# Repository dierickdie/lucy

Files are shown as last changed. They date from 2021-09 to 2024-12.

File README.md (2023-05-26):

# Lucy
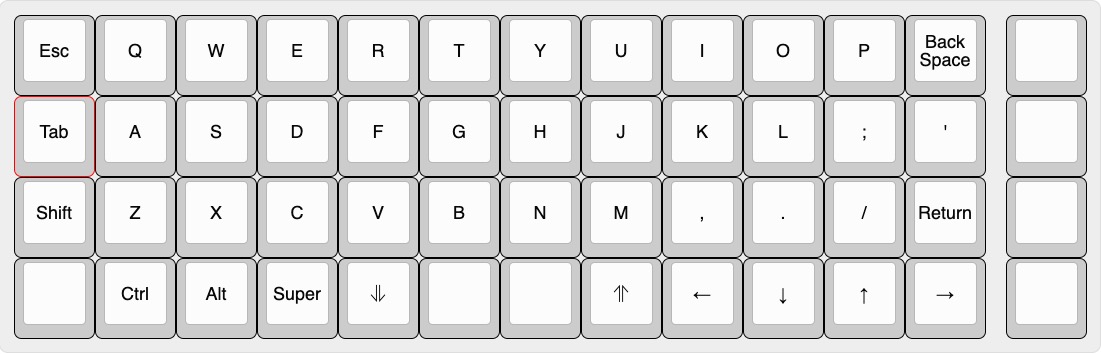
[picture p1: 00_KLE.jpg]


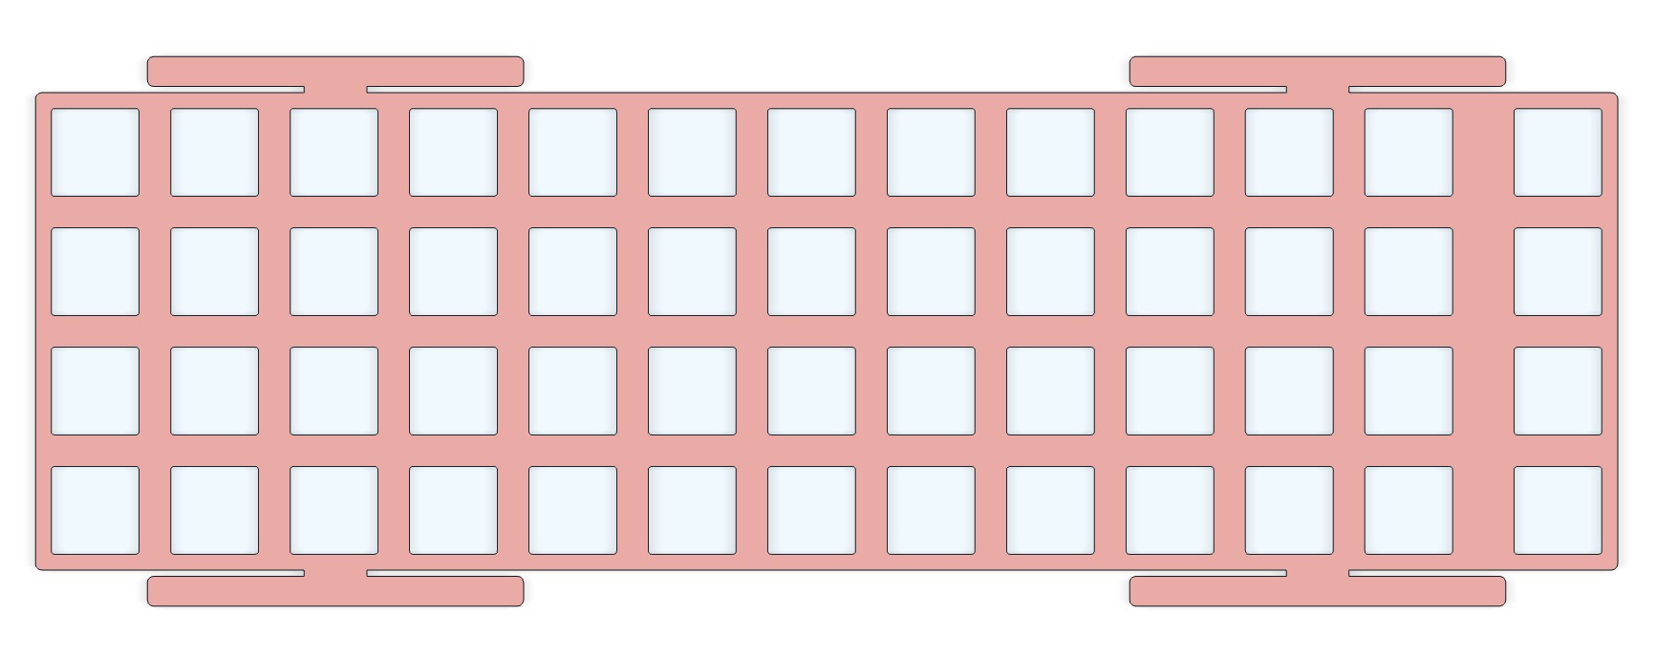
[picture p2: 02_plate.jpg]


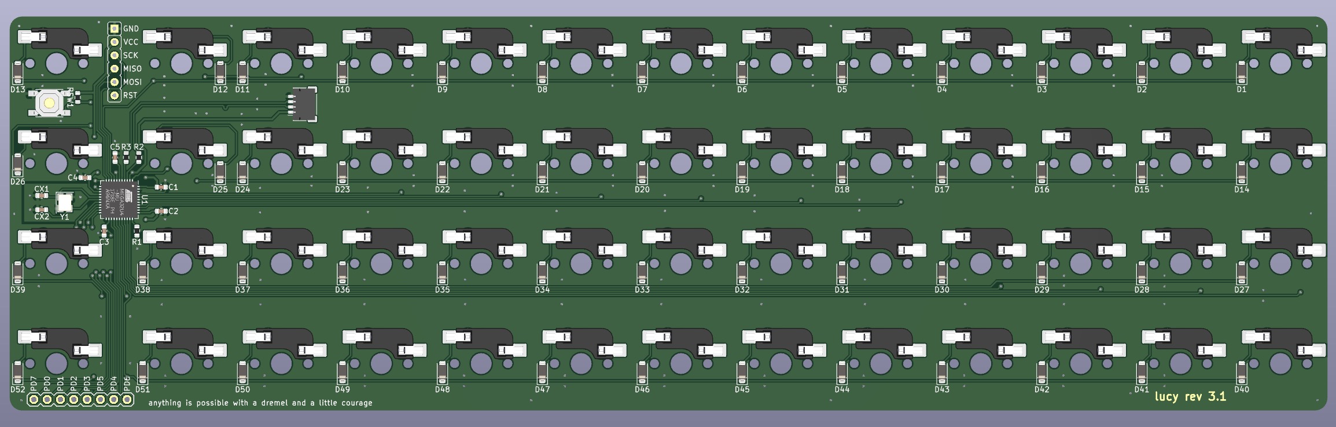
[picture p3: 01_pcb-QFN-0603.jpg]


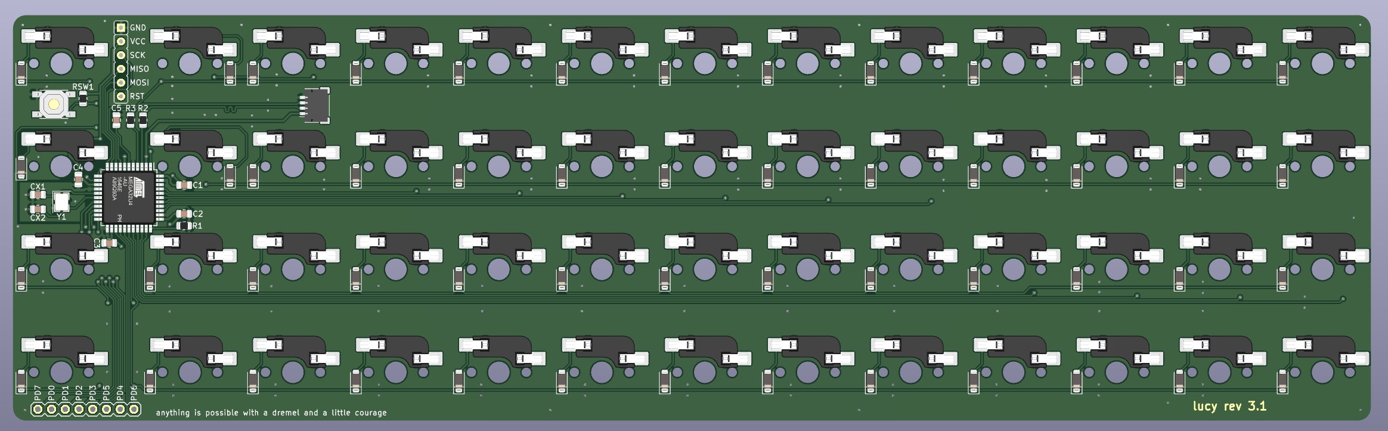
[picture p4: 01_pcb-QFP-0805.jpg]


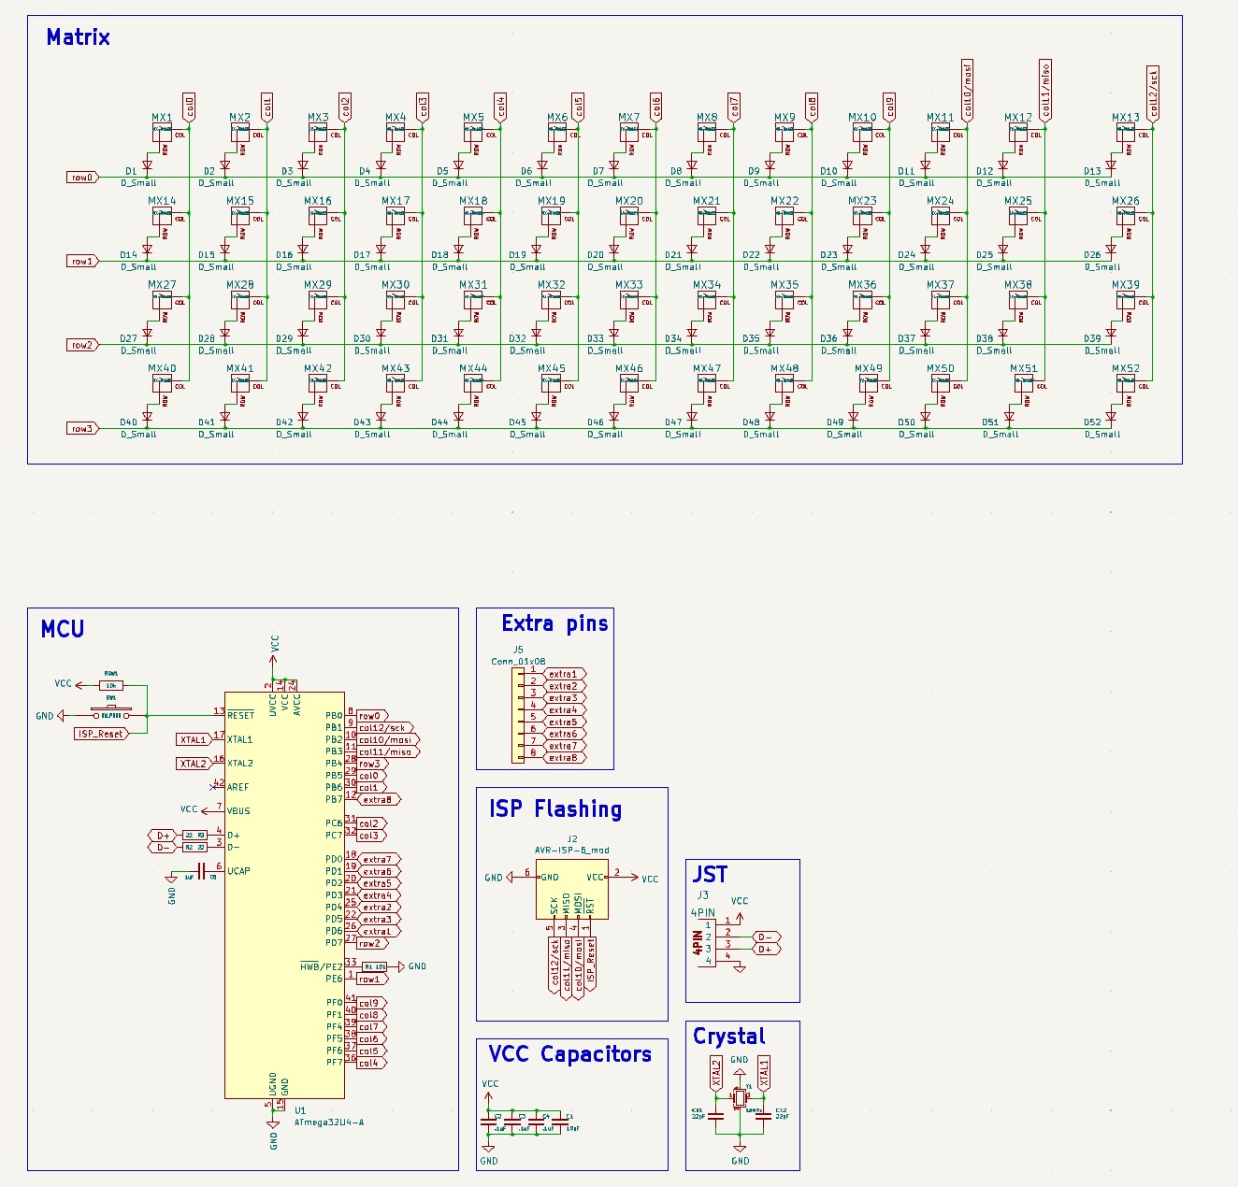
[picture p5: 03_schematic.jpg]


An 4x12 ortho plus macro column keyboard.

**USE AT YOUR OWN RISK!!!** I am not responsible for any dumb things you do. Like fry your computer, break anything, etc.

## FAQ:
#### Does it have MIT/2x2u/etc.? 
No. Grid for life

#### Does it have backlighting?
No

#### Does it have RGB?
No

#### Does it have hotswap?
~No~ Fine

#### Does it have Alps support?
No

#### Choc support?
No

#### Encoder?
Not anymore; they're are a dead meme

#### Flex cuts?
See response to encoder

#### Will you add any of these?
No

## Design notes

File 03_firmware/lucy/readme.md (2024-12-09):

# lucy

lucy

*A short description of the keyboard/project*

* Keyboard Maintainer: [rick](https://github.com/therick0996)
* Hardware Supported: *The PCBs, controllers supported*
* Hardware Availability: *Links to where you can find this hardware*

Make example for this keyboard (after setting up your build environment):

    make lucy:default

Flashing example for this keyboard:

    make lucy:default:flash

See the [build environment setup](https://docs.qmk.fm/#/getting_started_build_tools) and the [make instructions](https://docs.qmk.fm/#/getting_started_make_guide) for more information. Brand new to QMK? Start with our [Complete Newbs Guide](https://docs.qmk.fm/#/newbs).

## Bootloader

Enter the bootloader in 3 ways:

* **Bootmagic reset**: Hold down the key at (0,0) in the matrix (usually the top left key or Escape) and plug in the keyboard
* **Physical reset button**: Briefly press the button on the back of the PCB - some may have pads you must short instead
* **Keycode in layout**: Press the key mapped to `QK_BOOT` if it is available

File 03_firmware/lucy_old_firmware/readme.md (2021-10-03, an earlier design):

A PCB I made for funsies

Make example for this keyboard (after setting up your build environment):  

    make lucy:default:dfu

See [build environment setup](https://docs.qmk.fm/build_environment_setup.html) then the [make instructions](https://docs.qmk.fm/make_instructions.html) for more information.

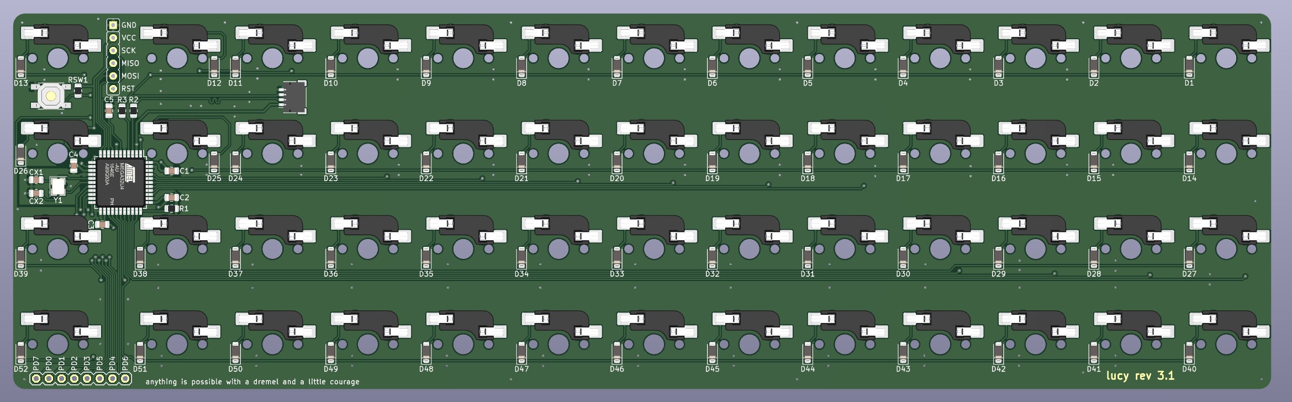
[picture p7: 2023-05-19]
02_pcb-QFP-0805.jpg

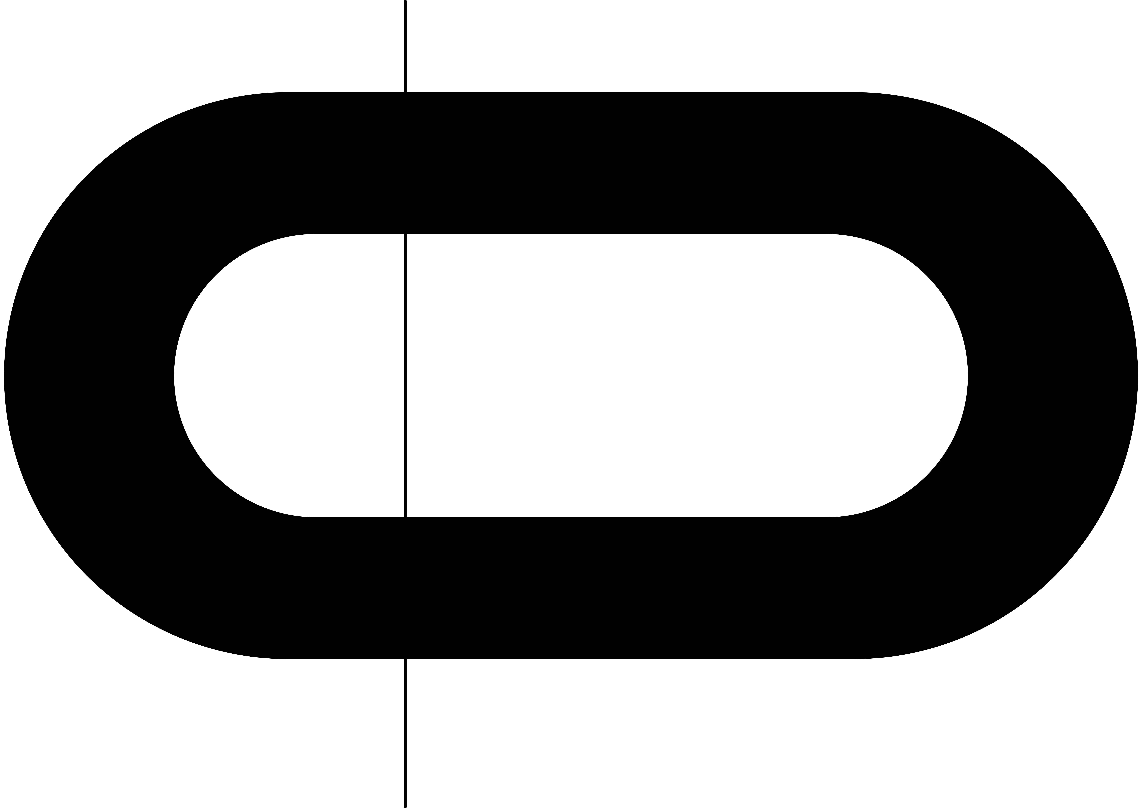
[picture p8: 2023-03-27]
01_pcb/3.0-QFN-0603/footprints/AcheronLibrary-master/svgs/sideHole.png

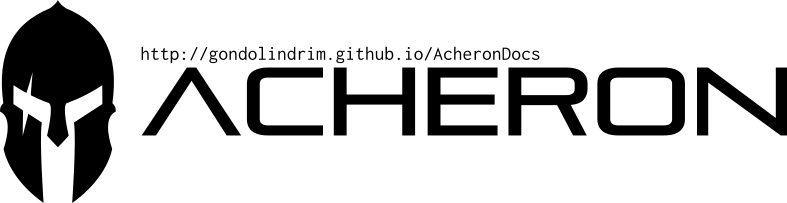
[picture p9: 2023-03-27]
01_pcb/3.0-QFN-0603/footprints/AcheronLibrary-master/graphics/acheronReadme.png

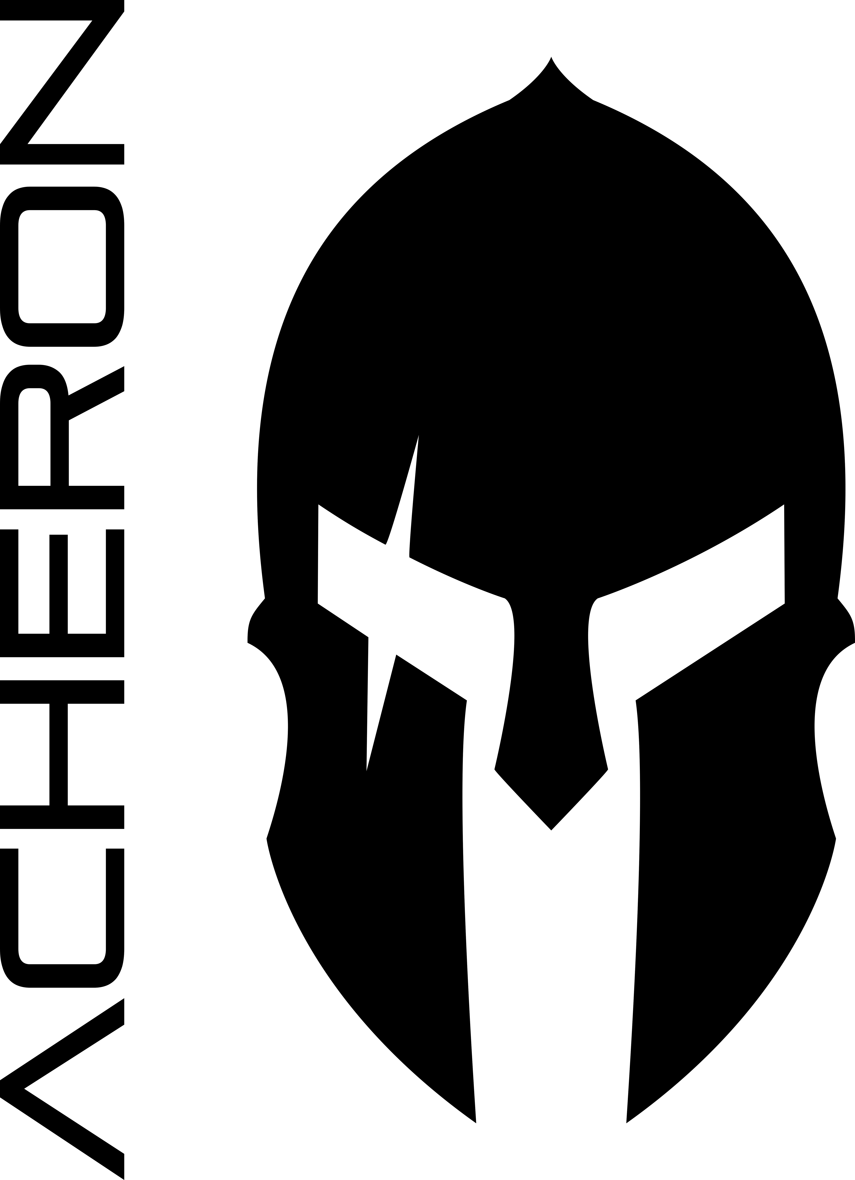
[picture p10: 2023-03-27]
01_pcb/3.0-QFN-0603/footprints/AcheronLibrary-master/graphics/acheronShort.png

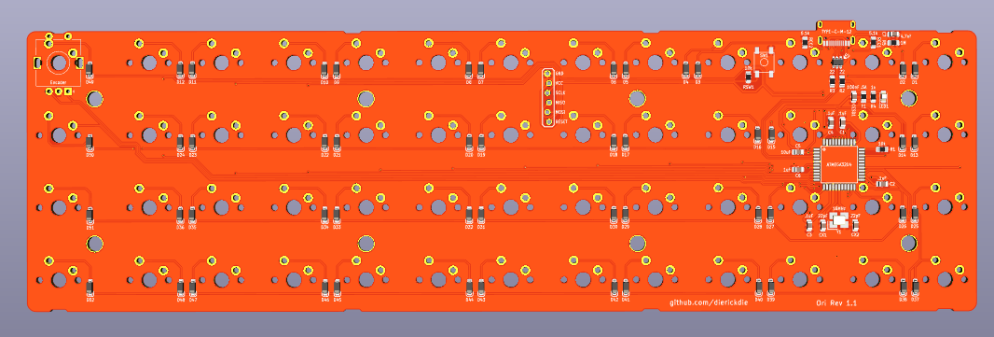
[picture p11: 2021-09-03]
01.1_non-snap-off/01_ori.png

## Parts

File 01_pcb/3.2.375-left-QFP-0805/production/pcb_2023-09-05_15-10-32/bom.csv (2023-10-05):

Designator | Footprint | Quantity | Value | LCSC Part #
C1 | 0805 | 1 | 10uF
C2, C3, C4 | 0805 | 3 | .1uF
C5 | 0805 | 1 | 1uF
CX1, CX2 | 0805 | 2 | 22pF
D1, D10, D11, D12, D13, D14, D15, D16, D17, D18, D19, D2, D20, D21, D22, D23, D24, D25, D26, D27, D28, D29, D3, D30, D31, D32, D33, D34, D35, D36, D37, D38, D39, D4, D40, D41, D42, D43, D44, D45, D46, D47, D48, D49, D5, D50, D51, D52, D6, D7, D8, D9 | D_SOD-123 | 52 | D_Small
J2 | PinHeader_1x6_P2.54mm_Vertical | 1 | AVR-ISP-6_mod
J3 | JST_SH_SM04B-SRSS-TB_1x04-1MP_P1.00mm_Horizontal | 1 | 4PIN
J5 | PinSocket_1x08_P2.54mm_Vertical | 1 | Conn_01x08
MX1, MX10, MX11, MX12, MX13, MX14, MX15, MX16, MX17, MX18, MX19, MX2, MX20, MX21, MX22, MX23, MX24, MX25, MX26, MX27, MX28, MX29, MX3, MX30, MX31, MX32, MX33, MX34, MX35, MX36, MX37, MX38, MX39, MX4, MX40, MX41, MX42, MX43, MX44, MX45, MX46, MX47, MX48, MX49, MX5, MX50, MX51, MX52, MX6, MX7, MX8, MX9 | SW_MX_HS_S_1u | 52 | MX-NoLED
R1, RSW1 | 0805 | 2 | 10k
R2, R3 | 0805 | 2 | 22
SW1 | SKQG-1155865 | 1 | SW_PUSH
U1 | TQFP-44_10x10mm_P0.8mm | 1 | ATmega32U4-A
Y1 | Crystal_SMD_3225-4Pin_3.2x2.5mm | 1 | 16MHz

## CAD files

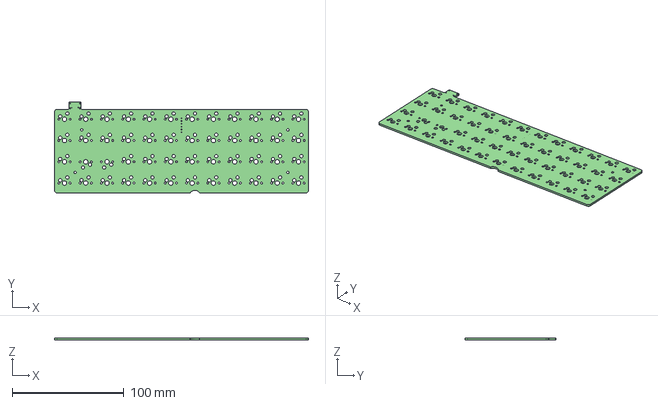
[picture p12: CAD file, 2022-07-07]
01_pcb/1.9 hotswap_no_macro/pcb.step
227.4 x 81.6 x 1.60 mm

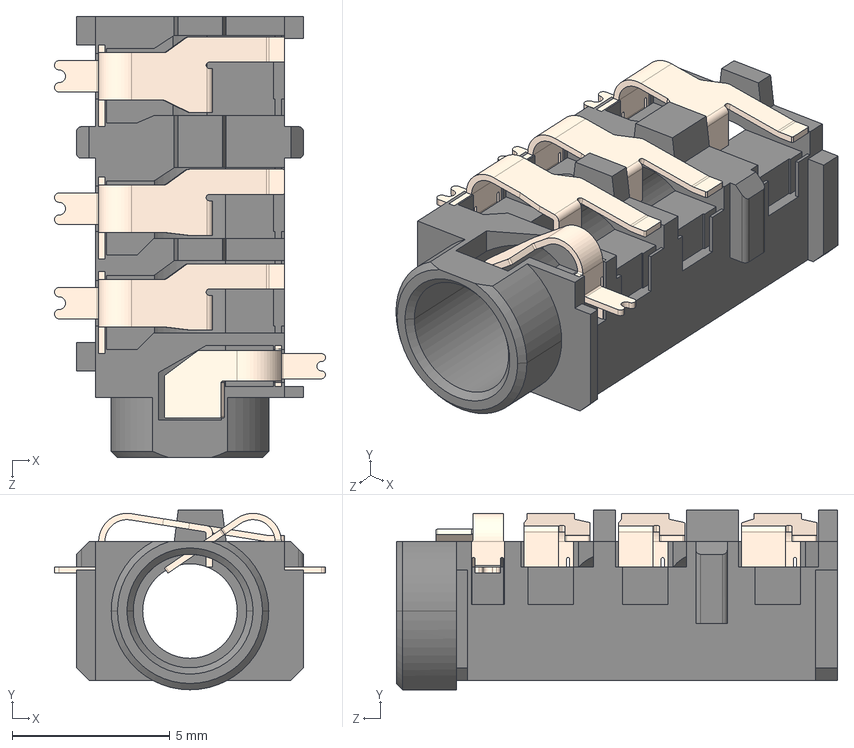
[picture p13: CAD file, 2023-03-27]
01_pcb/2.3 hotswap/footprints/Keebio-Parts.pretty-master/3dmodels/CUI_SJ-43614-SMT-TR.step
8.60 x 5.70 x 14.0 mm

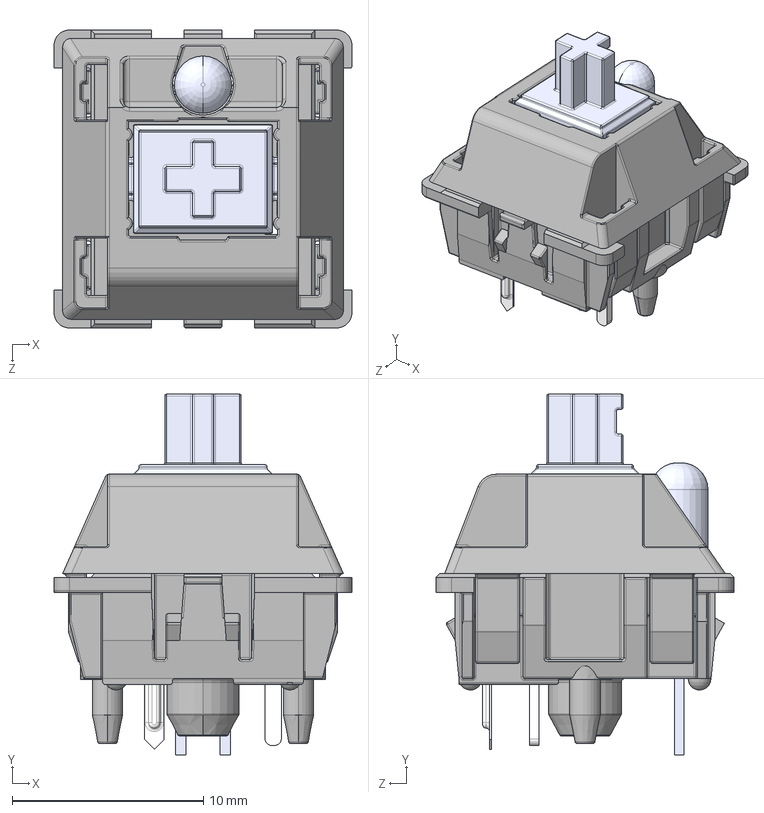
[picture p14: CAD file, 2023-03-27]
01_pcb/3.0-QFN-0603/footprints/AcheronLibrary-master/3d_models/mx_switch.step
15.6 x 18.9 x 15.6 mm
MX 轴 按键′_ü___¨1
MX 轴 轴体áì_¨￠¨__
MX粣 拸簽LEDLEDLED
MX轴 轴体 底部 μ×2__默认_á2____è_
针脚___默认__è_

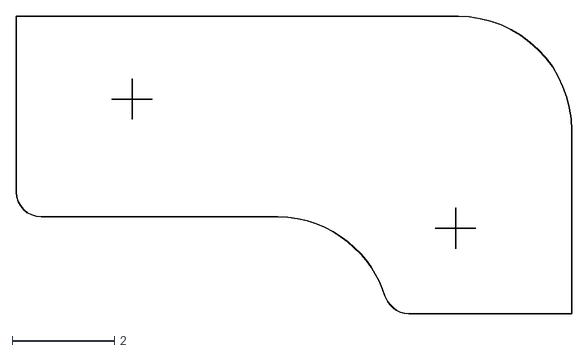
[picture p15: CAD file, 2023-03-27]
01_pcb/3.0-QFN-0603/footprints/AcheronLibrary-master/graphics/kailhMxSocketOutline.dxf
10.8 x 5.81

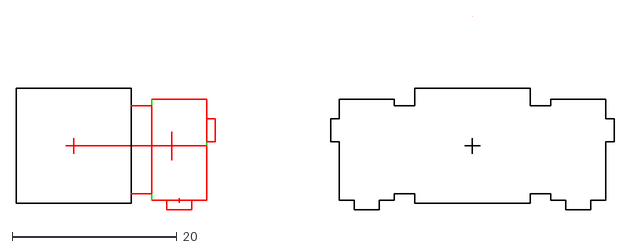
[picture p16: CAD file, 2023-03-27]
01_pcb/3.0-QFN-0603/footprints/AcheronLibrary-master/graphics/plate_cutouts/2U_switch_plate_cutout.dxf
72.6 x 23.5

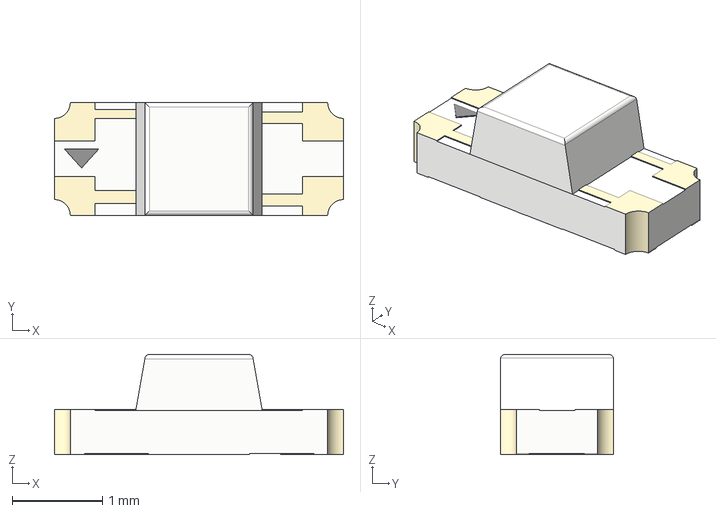
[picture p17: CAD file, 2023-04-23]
01_pcb/3.0-QFN-0603/footprints/marbastlib-main/3dmodels/LED_MHT151RGBCT.step
3.20 x 1.25 x 1.11 mm

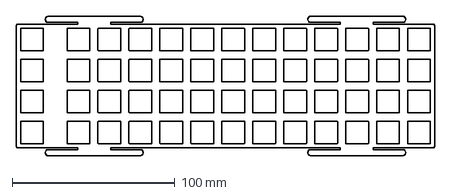
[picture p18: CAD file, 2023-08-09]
02_plate/plate-.375.dxf
257.2 x 85.7 mm

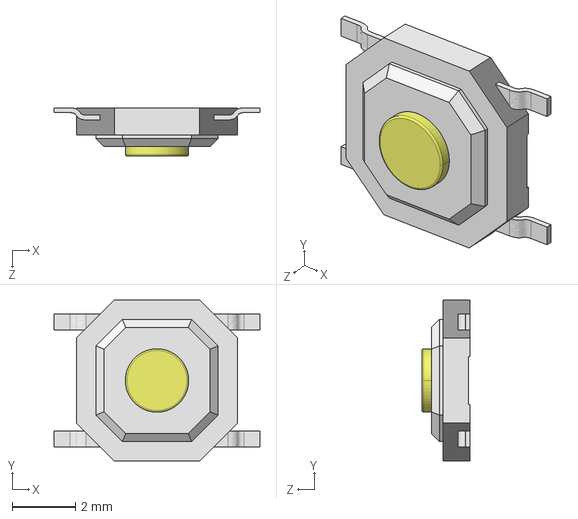
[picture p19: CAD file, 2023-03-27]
01_pcb/3.0-QFN-0603/footprints/AcheronLibrary-master/3d_models/Tactile_SMD_PushBtn_5x5mm.STEP
6.50 x 5.08 x 1.52 mm

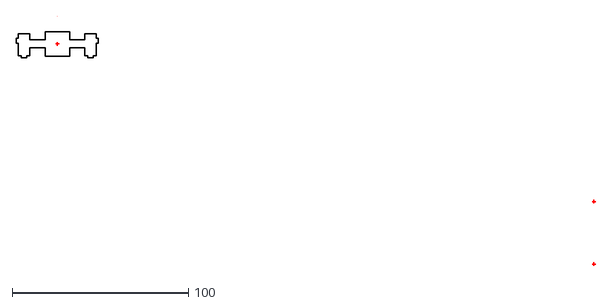
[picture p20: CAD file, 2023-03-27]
01_pcb/3.0-QFN-0603/footprints/AcheronLibrary-master/graphics/plate_cutouts/3U.dxf
329.0 x 141.8

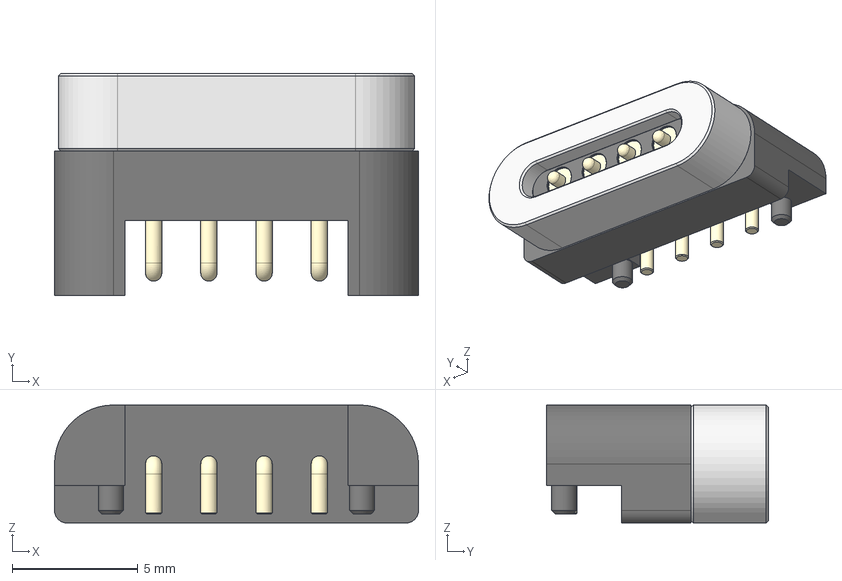
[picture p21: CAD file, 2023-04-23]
01_pcb/3.0-QFN-0603/footprints/marbastlib-main/3dmodels/CON_HytePro_M411P_Receptacle_1x04.step
14.5 x 8.85 x 4.70 mm
Magnetic Connector Female - MiddlePart
Magnetic Connector Female-tip_Standard
Magnetic Connector Female v2 - MountingPart

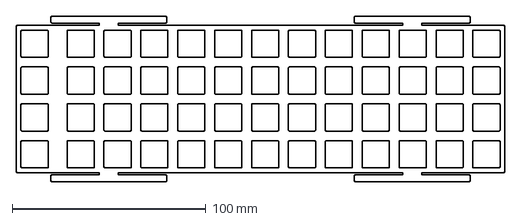
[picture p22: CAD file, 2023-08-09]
02_plate/plate-.1875.dxf
252.4 x 85.7 mm

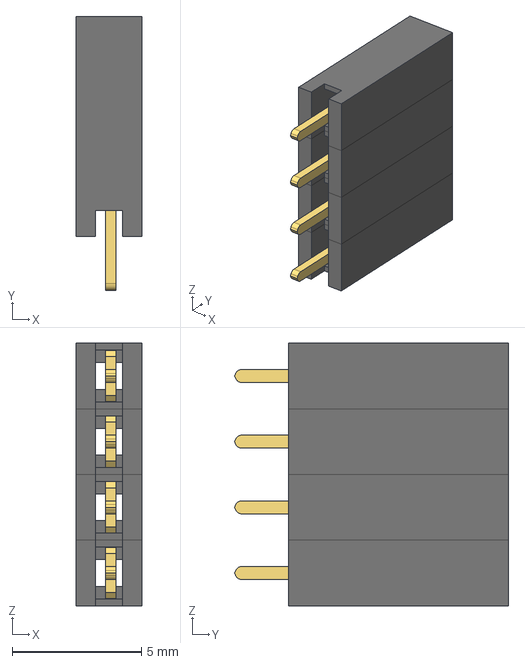
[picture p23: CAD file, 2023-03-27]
01_pcb/3.0-QFN-0603/footprints/AcheronLibrary-master/3d_models/4PinHeader.step
2.54 x 10.6 x 10.2 mm
header-1 x 4
pin-1 x 4

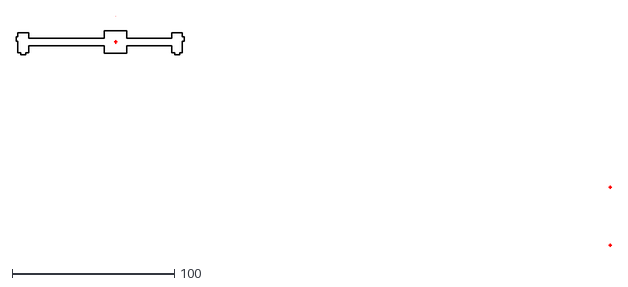
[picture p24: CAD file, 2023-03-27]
01_pcb/3.0-QFN-0603/footprints/AcheronLibrary-master/graphics/plate_cutouts/6U.dxf
367.0 x 141.8

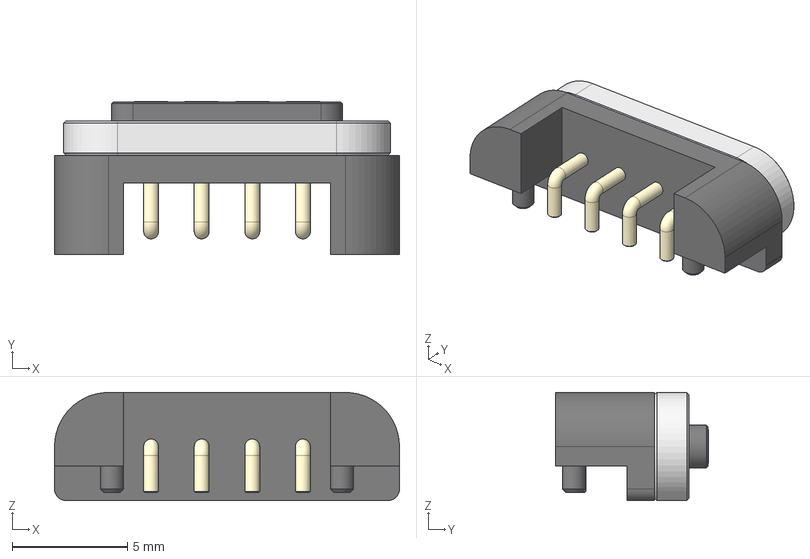
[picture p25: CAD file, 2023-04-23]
01_pcb/3.0-QFN-0603/footprints/marbastlib-main/3dmodels/CON_HytePro_M411P_Plug_1x04.step
15.0 x 6.64 x 4.70 mm
Magnetic Connector Male - MiddlePart
Magnetic Connector Male - MountingPart
Magnetic Connector Male-tip_Standard

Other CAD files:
02_plate/plate.dxf
01_pcb/3.0-QFN-0603/footprints/AcheronLibrary-master/3d_models/ACM2012-2P.STEP
01_pcb/3.0-QFN-0603/footprints/AcheronLibrary-master/graphics/plate_cutouts/7U.dxf
01_pcb/3.0-QFN-0603/footprints/marbastlib-main/3dmodels/CON_SM13B-SRSS-TB.step
01_pcb/3.0-QFN-0603/footprints/AcheronLibrary-master/3d_models/3313J-1-202E.stp
01_pcb/3.0-QFN-0603/footprints/AcheronLibrary-master/3d_models/5032_XTAL.step
01_pcb/3.0-QFN-0603/footprints/AcheronLibrary-master/3d_models/6028SMDRGB.iges
01_pcb/3.0-QFN-0603/footprints/AcheronLibrary-master/3d_models/ALPS_EC11E.stp
01_pcb/3.0-QFN-0603/footprints/AcheronLibrary-master/3d_models/BM04B-ASRS-TF.STEP
01_pcb/3.0-QFN-0603/footprints/AcheronLibrary-master/3d_models/E6C1209RGB.iges
01_pcb/3.0-QFN-0603/footprints/AcheronLibrary-master/3d_models/FUSE_1812.STEP
01_pcb/3.0-QFN-0603/footprints/AcheronLibrary-master/3d_models/MDBT40.step
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

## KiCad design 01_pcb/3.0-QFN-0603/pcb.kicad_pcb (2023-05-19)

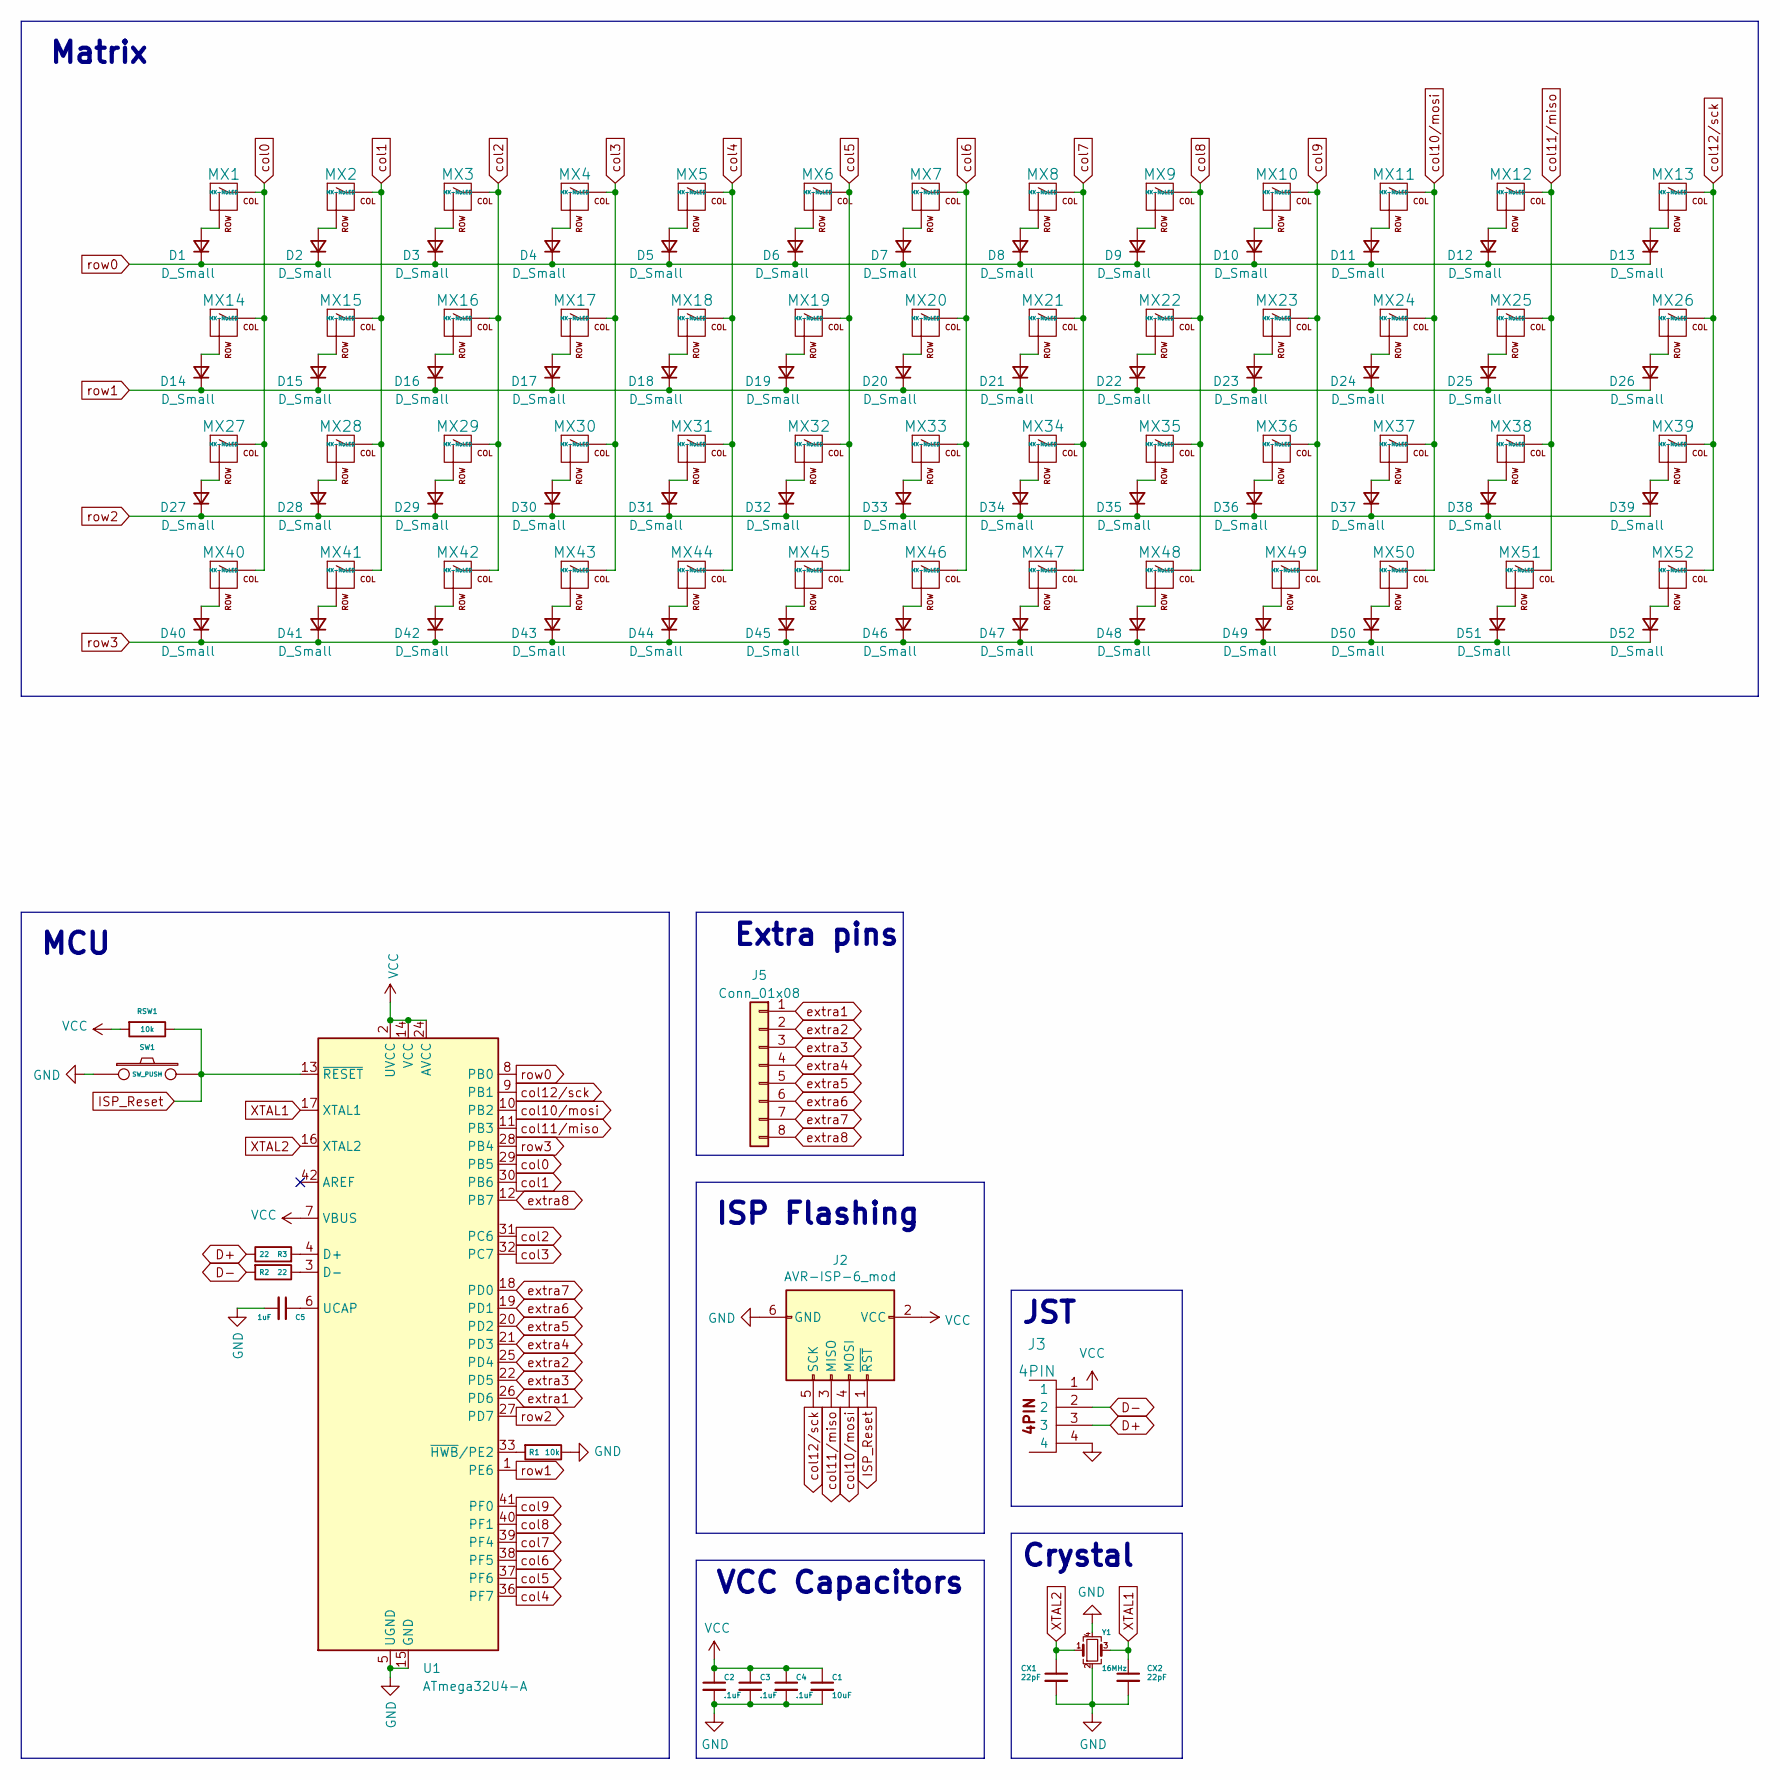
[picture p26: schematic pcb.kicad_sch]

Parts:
C1: 10uF; C_0603_1608Metric
C2, C3, C4: .1uF; C_0603_1608Metric
C5: 1uF; C_0603_1608Metric
CX1, CX2: 22pF; C_0603_1608Metric
D1, D2, D3, D4, D5, D6, D7, D8, D9, D10, D11, D12, D13, D14, D15, D16, D17, D18, D19, D20, D21, D22, D23, D24, D25, D26, D27, D28, D29, D30, D31, D32, D33, D34, D35, D36, D37, D38, D39, D40, D41, D42, D43, D44, D45, D46, D47, D48, D49, D50, D51, D52: D_Small; D_SOD-123
J2: AVR-ISP-6_mod; PinHeader_1x6_P2.54mm_Vertical
J3: 4PIN; JST_SH_SM04B-SRSS-TB_1x04-1MP_P1.00mm_Horizontal
J5: Conn_01x08; PinSocket_1x08_P2.54mm_Vertical
MX1, MX2, MX3, MX4, MX5, MX6, MX7, MX8, MX9, MX10, MX11, MX12, MX13, MX14, MX15, MX16, MX17, MX18, MX19, MX20, MX21, MX22, MX23, MX24, MX25, MX26, MX27, MX28, MX29, MX30, MX31, MX32, MX33, MX34, MX35, MX36, MX37, MX38, MX39, MX40, MX41, MX42, MX43, MX44, MX45, MX46, MX47, MX48, MX49, MX50, MX51, MX52: MX-NoLED; SW_MX_HS_S_1u
R1: 10k; R_0603_1608Metric
R2, R3: 22; R_0603_1608Metric
RSW1: 10k; R_0603_1608Metric
SW1: SW_PUSH; SKQG-1155865
U1: ATmega32U4-A; QFN-44-1EP_7x7mm_P0.5mm_EP5.2x5.2mm
Y1: 16MHz; Crystal_SMD_3225-4Pin_3.2x2.5mm

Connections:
D+: J3.3, R3.1
D-: J3.2, R2.2
GND: C1.2, C2.2, C3.2, C4.2, C5.2, CX1.2, CX2.2, J2.6 (GND), J3.4, R1.1, SW1.1, U1.5 (UGND), U1.15 (GND), U1.23 (GND), U1.35 (GND), U1.43 (GND), U1.45, Y1.2, Y1.4
ISP_Reset: J2.1 (~RST), RSW1.1, SW1.2, U1.13 (~RESET)
unnamed: D1.2 (A), MX1.2 (ROW)
unnamed: D2.2 (A), MX2.2 (ROW)
unnamed: D3.2 (A), MX3.2 (ROW)
unnamed: D4.2 (A), MX4.2 (ROW)
unnamed: D5.2 (A), MX5.2 (ROW)
unnamed: D6.2 (A), MX6.2 (ROW)
unnamed: D7.2 (A), MX7.2 (ROW)
unnamed: D8.2 (A), MX8.2 (ROW)
unnamed: D9.2 (A), MX9.2 (ROW)
unnamed: D10.2 (A), MX10.2 (ROW)
unnamed: D11.2 (A), MX11.2 (ROW)
unnamed: D12.2 (A), MX12.2 (ROW)
unnamed: D13.2 (A), MX13.2 (ROW)
unnamed: D14.2 (A), MX14.2 (ROW)
unnamed: D15.2 (A), MX15.2 (ROW)
unnamed: D16.2 (A), MX16.2 (ROW)
unnamed: D17.2 (A), MX17.2 (ROW)
unnamed: D18.2 (A), MX18.2 (ROW)
unnamed: D19.2 (A), MX19.2 (ROW)
unnamed: D20.2 (A), MX20.2 (ROW)
unnamed: D21.2 (A), MX21.2 (ROW)
unnamed: D22.2 (A), MX22.2 (ROW)
unnamed: D23.2 (A), MX23.2 (ROW)
unnamed: D24.2 (A), MX24.2 (ROW)
unnamed: D25.2 (A), MX25.2 (ROW)
unnamed: D26.2 (A), MX26.2 (ROW)
unnamed: D27.2 (A), MX27.2 (ROW)
unnamed: D28.2 (A), MX28.2 (ROW)
unnamed: D29.2 (A), MX29.2 (ROW)
unnamed: D30.2 (A), MX30.2 (ROW)
unnamed: D31.2 (A), MX31.2 (ROW)
unnamed: D32.2 (A), MX32.2 (ROW)
unnamed: D33.2 (A), MX33.2 (ROW)
unnamed: D34.2 (A), MX34.2 (ROW)
unnamed: D35.2 (A), MX35.2 (ROW)
unnamed: D36.2 (A), MX36.2 (ROW)
unnamed: D37.2 (A), MX37.2 (ROW)
unnamed: D38.2 (A), MX38.2 (ROW)
unnamed: D39.2 (A), MX39.2 (ROW)
unnamed: D40.2 (A), MX40.2 (ROW)
unnamed: D41.2 (A), MX41.2 (ROW)
unnamed: D42.2 (A), MX42.2 (ROW)
unnamed: D43.2 (A), MX43.2 (ROW)
unnamed: D44.2 (A), MX44.2 (ROW)
unnamed: D45.2 (A), MX45.2 (ROW)
unnamed: D46.2 (A), MX46.2 (ROW)
unnamed: D47.2 (A), MX47.2 (ROW)
unnamed: D48.2 (A), MX48.2 (ROW)
unnamed: D49.2 (A), MX49.2 (ROW)
unnamed: D50.2 (A), MX50.2 (ROW)
unnamed: D51.2 (A), MX51.2 (ROW)
unnamed: D52.2 (A), MX52.2 (ROW)
unnamed: R3.2, U1.4 (D+)
unnamed: R2.1, U1.3 (D-)
unnamed: C5.1, U1.6 (UCAP)
unnamed: R1.2, U1.33 (~HWB/PE2)
VCC: C1.1, C2.1, C3.1, C4.1, J2.2 (VCC), J3.1, RSW1.2, U1.2 (UVCC), U1.7 (VBUS), U1.14 (VCC), U1.24 (AVCC), U1.34 (VCC), U1.44 (AVCC)
XTAL1: CX2.1, U1.17 (XTAL1), Y1.3
XTAL2: CX1.1, U1.16 (XTAL2), Y1.1
col0: MX1.1 (COL), MX14.1 (COL), MX27.1 (COL), MX40.1 (COL), U1.29 (PB5)
col1: MX2.1 (COL), MX15.1 (COL), MX28.1 (COL), MX41.1 (COL), U1.30 (PB6)
col2: MX3.1 (COL), MX16.1 (COL), MX29.1 (COL), MX42.1 (COL), U1.31 (PC6)
col3: MX4.1 (COL), MX17.1 (COL), MX30.1 (COL), MX43.1 (COL), U1.32 (PC7)
col4: MX5.1 (COL), MX18.1 (COL), MX31.1 (COL), MX44.1 (COL), U1.36 (PF7)
col5: MX6.1 (COL), MX19.1 (COL), MX32.1 (COL), MX45.1 (COL), U1.37 (PF6)
col6: MX7.1 (COL), MX20.1 (COL), MX33.1 (COL), MX46.1 (COL), U1.38 (PF5)
col7: MX8.1 (COL), MX21.1 (COL), MX34.1 (COL), MX47.1 (COL), U1.39 (PF4)
col8: MX9.1 (COL), MX22.1 (COL), MX35.1 (COL), MX48.1 (COL), U1.40 (PF1)
col9: MX10.1 (COL), MX23.1 (COL), MX36.1 (COL), MX49.1 (COL), U1.41 (PF0)
col10/mosi: J2.4 (MOSI), MX11.1 (COL), MX24.1 (COL), MX37.1 (COL), MX50.1 (COL), U1.10 (PB2)
col11/miso: J2.3 (MISO), MX12.1 (COL), MX25.1 (COL), MX38.1 (COL), MX51.1 (COL), U1.11 (PB3)
col12/sck: J2.5 (SCK), MX13.1 (COL), MX26.1 (COL), MX39.1 (COL), MX52.1 (COL), U1.9 (PB1)
extra1: J5.1, U1.26 (PD6)
extra2: J5.2, U1.25 (PD4)
extra3: J5.3, U1.22 (PD5)
extra4: J5.4, U1.21 (PD3)
extra5: J5.5, U1.20 (PD2)
extra6: J5.6, U1.19 (PD1)
extra7: J5.7, U1.18 (PD0)
extra8: J5.8, U1.12 (PB7)
row0: D1.1 (K), D2.1 (K), D3.1 (K), D4.1 (K), D5.1 (K), D6.1 (K), D7.1 (K), D8.1 (K), D9.1 (K), D10.1 (K), D11.1 (K), D12.1 (K), D13.1 (K), U1.8 (PB0)
row1: D14.1 (K), D15.1 (K), D16.1 (K), D17.1 (K), D18.1 (K), D19.1 (K), D20.1 (K), D21.1 (K), D22.1 (K), D23.1 (K), D24.1 (K), D25.1 (K), D26.1 (K), U1.1 (PE6)
row2: D27.1 (K), D28.1 (K), D29.1 (K), D30.1 (K), D31.1 (K), D32.1 (K), D33.1 (K), D34.1 (K), D35.1 (K), D36.1 (K), D37.1 (K), D38.1 (K), D39.1 (K), U1.27 (PD7)
row3: D40.1 (K), D41.1 (K), D42.1 (K), D43.1 (K), D44.1 (K), D45.1 (K), D46.1 (K), D47.1 (K), D48.1 (K), D49.1 (K), D50.1 (K), D51.1 (K), D52.1 (K), U1.28 (PB4)

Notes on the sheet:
ISP Flashing
Matrix
VCC Capacitors
Crystal
Extra pins
JST
MCU

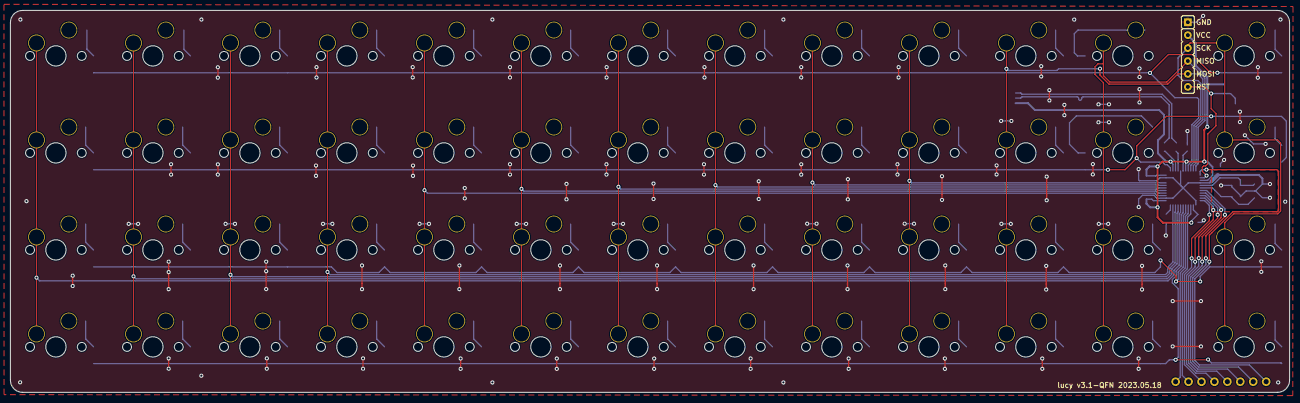
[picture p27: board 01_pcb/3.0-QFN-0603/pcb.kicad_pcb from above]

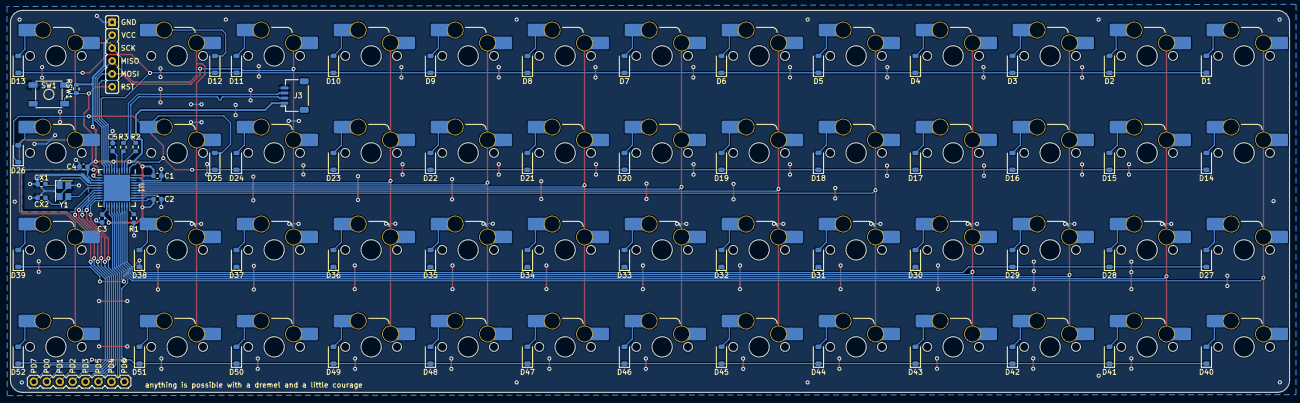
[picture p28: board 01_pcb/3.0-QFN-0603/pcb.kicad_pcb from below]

Board: 2 copper layers, 251.2 x 75.0 mm, 121 parts (121 on the bottom side), 88 nets.

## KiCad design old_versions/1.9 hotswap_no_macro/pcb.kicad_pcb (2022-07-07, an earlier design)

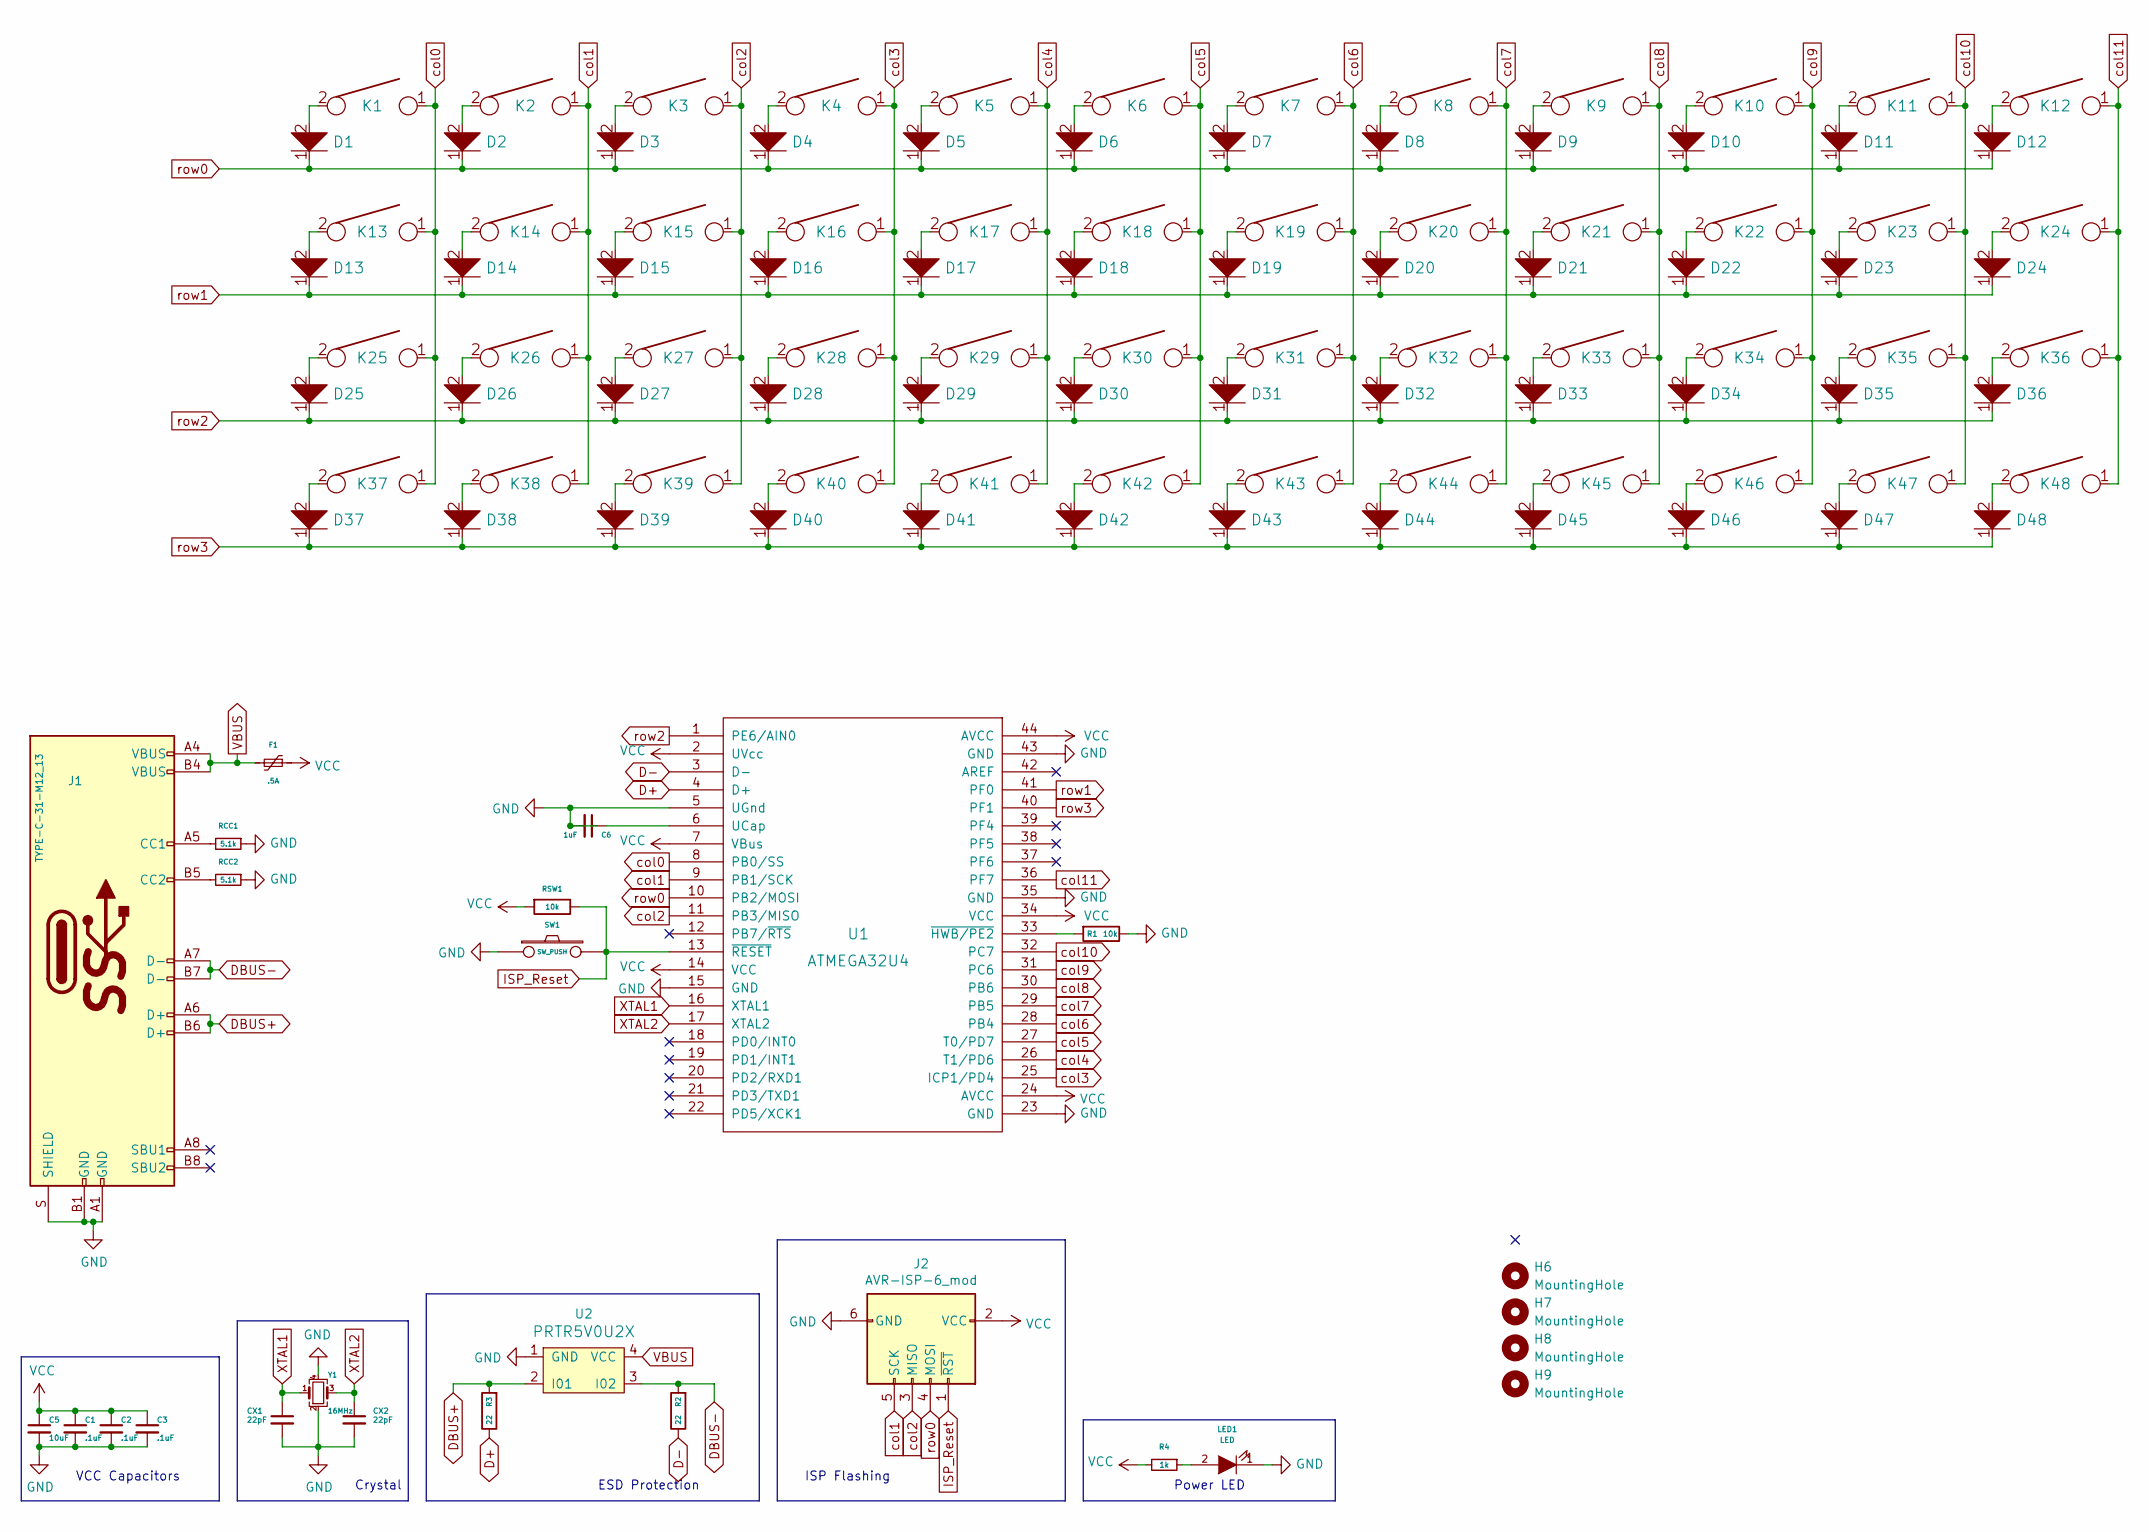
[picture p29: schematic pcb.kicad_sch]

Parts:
C1, C2, C3: .1uF; C_0805_2012Metric_Pad1.15x1.40mm_HandSolder
C5: 10uF; C_0805_2012Metric_Pad1.15x1.40mm_HandSolder
C6: 1uF; C_0805_2012Metric_Pad1.15x1.40mm_HandSolder
CX1, CX2: 22pF; C_0805_2012Metric_Pad1.15x1.40mm_HandSolder
D1, D2, D3, D4, D5, D6, D7, D8, D9, D10, D11, D12, D13, D14, D15, D16, D17, D18, D19, D20, D21, D22, D23, D24, D25, D26, D27, D28, D29, D30, D31, D32, D33, D34, D35, D36, D37, D38, D39, D40, D41, D42, D43, D44, D45, D46, D47, D48: D; D_SOD-123_modified
F1: .5A; Fuse_0805_2012Metric_Pad1.15x1.40mm_HandSolder
H6, H7, H8, H9: MountingHole; MountingHole_2.2mm_M2_DIN965_Pad
J1: TYPE-C-31-M12_13; TYPE-C-31-M-12
J2: AVR-ISP-6_mod; ICSP-Header_small_pins
K1, K2, K3, K4, K5, K6, K7, K8, K9, K10, K11, K12, K13, K14, K15, K16, K17, K18, K19, K20, K21, K22, K23, K24, K25, K26, K27, K28, K29, K30, K31, K32, K33, K34, K35, K36, K37, K38, K39, K40, K41, K42, K43, K44, K45, K46, K47, K48: KEYSW; MXOnly-1U-Hotswap
LED1: LED; LED_0805_2012Metric_Pad1.15x1.40mm_HandSolder
R1: 10k; R_0805_2012Metric_Pad1.15x1.40mm_HandSolder
R2, R3: 22; R_0805_2012Metric_Pad1.15x1.40mm_HandSolder
R4: 1k; R_0805_2012Metric_Pad1.15x1.40mm_HandSolder
RCC1, RCC2: 5.1k; R_0805_2012Metric_Pad1.15x1.40mm_HandSolder
RSW1: 10k; R_0805_2012Metric_Pad1.15x1.40mm_HandSolder
SW1: SW_PUSH; SKQG-1155865
U1: ATMEGA32U4; ATMEGA32U4-AU
U2: PRTR5V0U2X; SOT-143B
Y1: 16MHz; Crystal_SMD_3225-4Pin_3.2x2.5mm_HandSoldering

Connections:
D+: R3.1, U1.4 (D+)
D-: R2.1, U1.3 (D-)
DBUS+: J1.A6 (D+), J1.B6 (D+), R3.2, U2.2 (I01)
DBUS-: J1.A7 (D-), J1.B7 (D-), R2.2, U2.3 (I02)
GND: C1.2, C2.2, C3.2, C5.2, C6.2, CX1.2, CX2.2, J1.A1 (GND), J1.B1 (GND), J1.S (SHIELD), J2.6 (GND), LED1.1 (K), R1.1, RCC1.1, RCC2.1, SW1.1, U1.5 (UGnd), U1.15 (GND), U1.23 (GND), U1.35 (GND), U1.43 (GND), U2.1 (GND), Y1.2, Y1.4
ISP_Reset: J2.1 (~RST), RSW1.1, SW1.2, U1.13 (~RESET)
unnamed: C6.1, U1.6 (UCap)
unnamed: D1.2, K1.2
unnamed: D2.2, K2.2
unnamed: D3.2, K3.2
unnamed: D4.2, K4.2
unnamed: D5.2, K5.2
unnamed: D6.2, K6.2
unnamed: D7.2, K7.2
unnamed: D8.2, K8.2
unnamed: D9.2, K9.2
unnamed: D10.2, K10.2
unnamed 17: D11.2, K11.2; also elsewhere on the board
unnamed: D12.2, K12.2
unnamed: D13.2, K13.2
unnamed: D14.2, K14.2
unnamed: D15.2, K15.2
unnamed: D16.2, K16.2
unnamed: D17.2, K17.2
unnamed: D18.2, K18.2
unnamed: D19.2, K19.2
unnamed: D20.2, K20.2
unnamed: D21.2, K21.2
unnamed 28: D22.2, K22.2; also elsewhere on the board
unnamed: D23.2, K23.2
unnamed: D24.2, K24.2
unnamed: D25.2, K25.2
unnamed: D26.2, K26.2
unnamed: D27.2, K27.2
unnamed: D28.2, K28.2
unnamed: D29.2, K29.2
unnamed: D30.2, K30.2
unnamed: D31.2, K31.2
unnamed: D32.2, K32.2
unnamed: D33.2, K33.2
unnamed: D34.2, K34.2
unnamed 41: D35.2, K35.2; also elsewhere on the board
unnamed: D36.2, K36.2
unnamed: D37.2, K37.2
unnamed: D38.2, K38.2
unnamed: D39.2, K39.2
unnamed 46: D40.2, K40.2; also elsewhere on the board
unnamed 47: D41.2, K41.2; also elsewhere on the board
unnamed: D42.2, K42.2
unnamed: D43.2, K43.2
unnamed: D44.2, K44.2
unnamed: D45.2, K45.2
unnamed: D46.2, K46.2
unnamed: D47.2, K47.2
unnamed: D48.2, K48.2
unnamed: J1.A5 (CC1), RCC1.2
unnamed: J1.B5 (CC2), RCC2.2
unnamed: LED1.2 (A), R4.1
unnamed: R1.2, U1.33 (~HWB/PE2)
VBUS: F1.2, J1.A4 (VBUS), J1.B4 (VBUS), U2.4 (VCC)
VCC: C1.1, C2.1, C3.1, C5.1, F1.1, J2.2 (VCC), R4.2, RSW1.2, U1.2 (UVcc), U1.7 (VBus), U1.14 (VCC), U1.24 (AVCC), U1.34 (VCC), U1.44 (AVCC)
XTAL1: CX1.1, U1.16 (XTAL1), Y1.1
XTAL2: CX2.1, U1.17 (XTAL2), Y1.3
col0: K1.1, K13.1, K25.1, K37.1, U1.8 (PB0/SS)
col1: J2.5 (SCK), K2.1, K14.1, K26.1, K38.1, U1.9 (PB1/SCK)
col2: J2.3 (MISO), K3.1, K15.1, K27.1, K39.1, U1.11 (PB3/MISO)
col3: K4.1, K16.1, K28.1, K40.1, U1.25 (ICP1/PD4); also elsewhere on the board
col4: K5.1, K17.1, K29.1, K41.1, U1.26 (T1/PD6); also elsewhere on the board
col5: K6.1, K18.1, K30.1, K42.1, U1.27 (T0/PD7)
col6: K7.1, K19.1, K31.1, K43.1, U1.28 (PB4)
col7: K8.1, K20.1, K32.1, K44.1, U1.29 (PB5)
col8: K9.1, K21.1, K33.1, K45.1, U1.30 (PB6)
col9: K10.1, K22.1, K34.1, K46.1, U1.31 (PC6); also elsewhere on the board
col10: K11.1, K23.1, K35.1, K47.1, U1.32 (PC7); also elsewhere on the board
col11: K12.1, K24.1, K36.1, K48.1, U1.36 (PF7)
row0: D1.1, D2.1, D3.1, D4.1, D5.1, D6.1, D7.1, D8.1, D9.1, D10.1, D11.1, D12.1, J2.4 (MOSI), U1.10 (PB2/MOSI)
row1: D13.1, D14.1, D15.1, D16.1, D17.1, D18.1, D19.1, D20.1, D21.1, D22.1, D23.1, D24.1, U1.41 (PF0)
row2: D25.1, D26.1, D27.1, D28.1, D29.1, D30.1, D31.1, D32.1, D33.1, D34.1, D35.1, D36.1, U1.1 (PE6/AIN0)
row3: D37.1, D38.1, D39.1, D40.1, D41.1, D42.1, D43.1, D44.1, D45.1, D46.1, D47.1, D48.1, U1.40 (PF1)

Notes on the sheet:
ESD Protection
Crystal
Power LED
VCC Capacitors
ISP Flashing

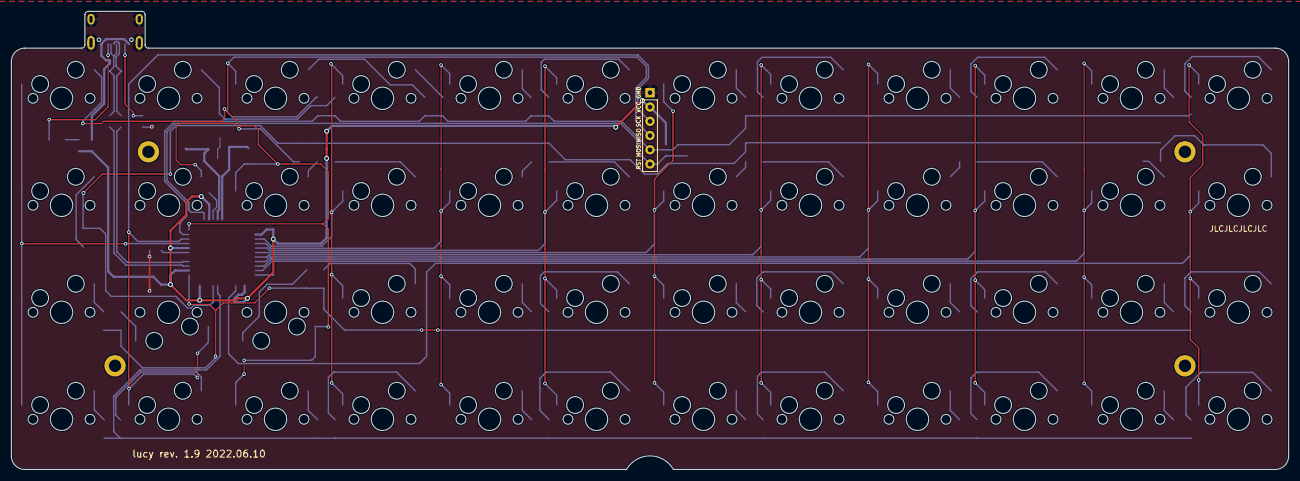
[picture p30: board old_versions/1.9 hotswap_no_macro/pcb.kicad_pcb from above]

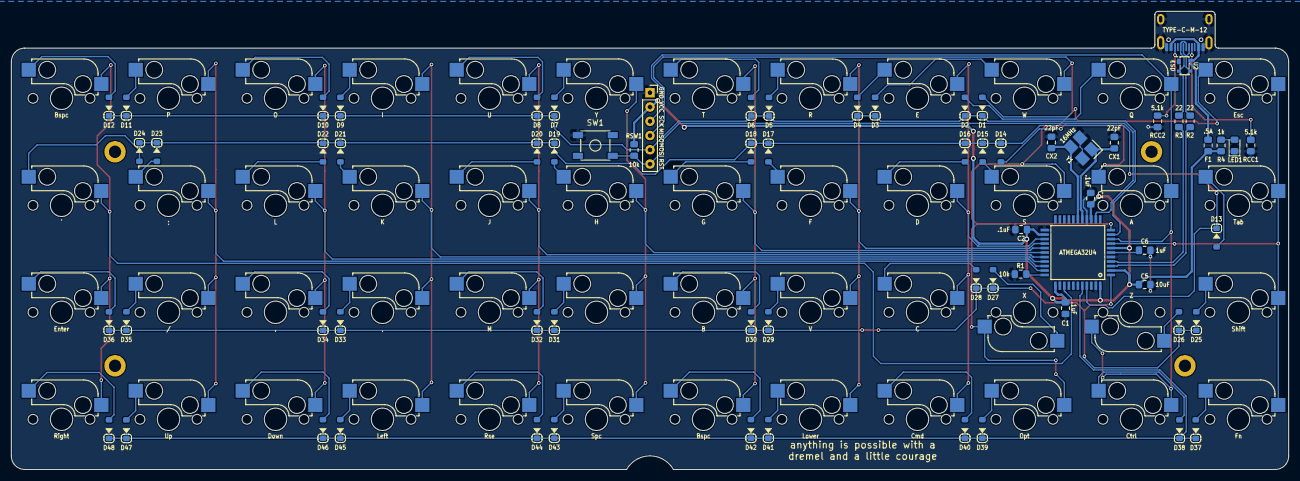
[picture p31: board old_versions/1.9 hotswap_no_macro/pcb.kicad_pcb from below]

Board: 2 copper layers, 227.4 x 81.6 mm, 122 parts (70 on the bottom side), 79 nets.

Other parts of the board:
locked: KEYSW; MXOnly-1U-Hotswap
locked#2, locked#3, locked#4, locked#5: KEYSW; MXOnly-1U-Hotswap

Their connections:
unnamed 17: locked.2; also elsewhere on the board
unnamed 28: locked#5.2; also elsewhere on the board
unnamed 41: locked#4.2; also elsewhere on the board
unnamed 46: locked#2.2; also elsewhere on the board
unnamed 47: locked#3.2; also elsewhere on the board
col3: locked#2.1; also elsewhere on the board
col4: locked#3.1; also elsewhere on the board
col9: locked#5.1; also elsewhere on the board
col10: locked.1, locked#4.1; also elsewhere on the board

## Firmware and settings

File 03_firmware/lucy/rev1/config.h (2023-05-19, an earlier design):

#pragma once

#include "config_common.h"

/* USB Device descriptor parameter */
#define VENDOR_ID       0x1337
#define PRODUCT_ID      0x0001
#define DEVICE_VER      0x0001
#define MANUFACTURER    therick
#define PRODUCT         lucy
#define DESCRIPTION     Blatant copy of a Planck plus a column

/* key matrix size */
#define MATRIX_ROWS 4
#define MATRIX_COLS 13

//lucy
#define MATRIX_ROW_PINS { B2, F0, E6, F1 }
#define MATRIX_COL_PINS { B0, B1, B3, D4, D6, D7, B4, B5, B6, C6, C7, F7,    F6}

//v3
//#define MATRIX_ROW_PINS { B0, E6, D7, B4 }
//#define MATRIX_COL_PINS { B5, B6, C6, C7, F7, F6, F5, F4, F1, F0, B2, B3,    B1 }


//ori
//#define MATRIX_ROW_PINS { F7, F6, D4, D6 }
//#define MATRIX_COL_PINS { D7, D5, B7, F5, F4, F1, F0, E6, B0, B1, B2, B3,    C6}

//therick48
//#define MATRIX_ROW_PINS { F7, F6, D4, D6 }
//#define MATRIX_COL_PINS { D7, D5, B7, F5, F4, F1, F0, E6, B0, B1, B2, B3,    C6 }

#define UNUSED_PINS

/* COL2ROW, ROW2COL, or CUSTOM_MATRIX */
#define DIODE_DIRECTION COL2ROW

/* Debounce reduces chatter (unintended double-presses) - set 0 if debouncing is not needed */
#define DEBOUNCING_DELAY 0

/* encoder support */
//#define ENCODERS_PAD_A { D3 }  // ori
//#define ENCODERS_PAD_B { D2 }  // ori
#define ENCODERS_PAD_A { F5 } // lucy
#define ENCODERS_PAD_B { F4 } // lucy

#define ENCODER_RESOLUTION 5

/* Mechanical locking support. Use KC_LCAP, KC_LNUM or KC_LSCR instead in keymap */
#define LOCKING_SUPPORT_ENABLE
/* Locking resynchronize hack */
#define LOCKING_RESYNC_ENABLE

#define BOOTMAGIC_LITE_ROW 0
#define BOOTMAGIC_LITE_COLUMN 0

// QMK-DFU
//#define QMK_ESC_OUTPUT F1  // COL pin if COL2ROW
//#define QMK_ESC_INPUT  D5  // ROW pin if COL2ROW
// Optional:
//#define QMK_LED E6
//#define QMK_SPEAKER C6

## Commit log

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2020-07-26 Routing data lines as differential pair
    [Ori-B_Cu.gbl, Ori-B_Mask.gbs, Ori-B_Paste.gbp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]
2020-07-26 Forgot to save schematic prior to last push
    [Ori.sch]
2020-08-03 Routed main VCC power trhough 10uF cap
    [Ori-B_Cu.gbl, Ori-B_Mask.gbs, Ori-B_Paste.gbp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]
2021-04-15 Create south facing LED PCB
    [Ori-B_Cu.gbl, Ori-B_Mask.gbs, Ori-B_Paste.gbp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]
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2021-04-26 update
    added macro column to top plate
    re-routed some traces
    new previews
    removed some ground plane
    [Ori-B_Cu.gbl, Ori-B_Mask.gbs, Ori-B_Paste.gbp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]
2021-05-08 Moved macro column a tiny bit
    [Ori-B_Cu.gbl, Ori-B_Mask.gbs, Ori-B_SilkS.gbo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]
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2021-07-12 19.05mm spacing; move macro column to right side
    [Ori.kicad_pcb, Ori.sch, Ori_bottom_plate.kicad_pcb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]
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2021-08-18 added different plate mounts
    [Ori_bottom_plate-B_Cu.gbr, Ori_bottom_plate-B_Mask.gbr, Ori_bottom_plate-B_Paste.gbr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]
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2021-08-21 add different top plates
    [ori-B_Cu.gbl, ori-B_Mask.gbs, ori-B_Paste.gbp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]
2021-08-22 add non break off column
    [Ori_bottom_plate-B_Cu.gbr, Ori_bottom_plate-B_Mask.gbr, Ori_bottom_plate-B_Paste.gbr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]
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2021-09-09 remove snap off version
    [ori-B_Cu.gbl, ori-B_Mask.gbs, ori-B_SilkS.gbo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]
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2021-09-09 move bottom mounting points and update previews
    [ori.kicad_pcb, ori_bottom_plate.kicad_pcb]
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2021-09-30 re-enabled mousekeys in keymap; moved 1.1 to old versions
    [ori-B_Cu.gbl, ori-B_Mask.gbs, ori-B_SilkS.gbo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]
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2021-10-03 replace ori references to lucy
    [lucy.kicad_pcb, lucy.sch, lucy_bottom_plate.kicad_pcb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]
2021-10-03 new gerbers with new name
    [lucy.kicad_pcb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]
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2021-10-09 add v1.2 - sent to JLC
    [lucy-B_Cu.gbl, lucy-B_Mask.gbs, lucy-B_SilkS.gbo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]
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2021-10-20 moved AREF pin to pin 1
    [pcb-B_Cu.gbl, pcb-B_Mask.gbs, pcb-B_SilkS.gbo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]
2021-10-24 create slots for top plate
    [bottom_plate-B_Cu.gbr, bottom_plate-B_Mask.gbr, bottom_plate-B_Paste.gbr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]
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2022-01-19 added HS pcb, new plate design
    [bottom (2).3mf, bottom (3).3mf, bottom_plate.kicad_pcb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]
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2022-03-21 Create hotswap PCB with all south facing switches
    [pcb.kicad_pcb, pcb.kicad_sch, pcb.sch]
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2022-03-24 removed switch opening slots
    [plate.kicad_pcb, plate.kicad_sch]
2022-03-24 nearly ready to send PCB to manu
    [pcb.kicad_pcb]
2022-03-28 making HS pcb flexy
    [pcb.kicad_pcb]
2022-03-28 some preliminary 3d files
    [Bottom-new-new.3mf, Bottomfiller.3mf, Lucy_v3 v13.3mf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]
2022-03-28 flex hs psb
    [pcb.kicad_pcb, pcb.kicad_sch, pcb.sch]
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2022-03-29 route lines away from crystal
    [pcb.kicad_pcb]
2022-03-29 remove temporary 3d files
    [Bottom-new-new.3mf, Bottom-new.3mf, Bottomfiller.3mf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]
2022-03-29 add mounting support for encoder
    [pcb.kicad_pcb, pcb.kicad_sch]
2022-04-11 pull old solder pcb
    current solder PCB was freezing in Kicad, pulled an old one and made changes. mostly just moved USB port up
    [pcb-B_Cu.gbl, pcb-B_Mask.gbs, pcb-B_Silkscreen.gbo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]
2022-04-11 remove old hotswap pcb
    remove hotswap pcb with north facing switches
    [pcb.kicad_pcb, pcb.kicad_sch, pcb.sch]
2022-04-11 rename flex hotswap pcb
    [pcb.kicad_pcb, pcb.kicad_sch, pcb.sch]
2022-04-18 added gasket mounting to plate
    [lucy_plate_hs.step, plate.kicad_pcb]
2022-04-18 update HS pcb; sent to manu
    [pcb-B_Cu.gbl, pcb-B_Mask.gbs, pcb-B_Silkscreen.gbo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]
2022-04-18 add gasket to plate
    [plate-B_Cu.gbr, plate-B_Mask.gbr, plate-B_Paste.gbr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]
2022-04-18 remove bottom fr4 pate
    [bottom_plate-B_Cu.gbr, bottom_plate-B_Mask.gbr, bottom_plate-B_Paste.gbr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]
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2022-04-19 updated plate for gasket
    [lucy_plate_hs.step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]
2022-04-20 add hs flex gerbers
    [pcb-B_Cu.gbl, pcb-B_Mask.gbs, pcb-B_Silkscreen.gbo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]
2022-04-20 flex plate
2022-04-20 add flex plate gerbers
    [plate-B_Cu.gbr, plate-B_Mask.gbr, plate-B_Paste.gbr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]
2022-04-20 add flex plate files
    [pcb.kicad_pcb, plate.kicad_pcb, plate.kicad_sch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]
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2022-04-20 archive v1.0 HS
    sorry github
    [pcb-B_Cu.gbl, pcb-B_Mask.gbs, pcb-B_Silkscreen.gbo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]
2022-04-20 archive v1.0 HS flex
    [pcb-B_Cu.gbl, pcb-B_Mask.gbs, pcb-B_Silkscreen.gbo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]
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2022-04-27 update flex plate - changed to version A
    [plate-B_Cu.gbr, plate-B_Mask.gbr, plate-B_Paste.gbr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]
2022-04-27 create flex plate ver. B
    [lucy_plate_hs_b.step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]
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2022-06-05 updated solder pcb files
    [pcb 2.kicad_pcb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]
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2022-06-05 remove old versions that weren't submitted
    [pcb-B_Cu.gbl, pcb-B_Mask.gbs, pcb-B_Silkscreen.gbo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]
2022-06-05 updated plate designs
    add gasket mounting, replaced slots with holes for top mount
    [plate-B_Cu.gbr, plate-B_Mask.gbr, plate-B_Paste.gbr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]
2022-06-05 remove old solder files
    [pcb 2.kicad_pcb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]
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2022-06-05 hotswap without flex cuts
    [pcb-B_Cu.gbl, pcb-B_Mask.gbs, pcb-B_Silkscreen.gbo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]
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2022-06-11 Remove old hotswap PCB without flex cuts
    [pcb-B_Cu.gbl, pcb-B_Mask.gbs, pcb-B_Silkscreen.gbo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]
2022-06-11 Remove old Plate A
    [plate.kicad_pcb, plate.kicad_sch, plate.sch]
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2022-06-11 include 1.9 and 2.0 pcbs
    [pcb-B_Cu.gbl, pcb-B_Mask.gbs, pcb-B_Silkscreen.gbo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]
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2022-07-07 move notch to center
    [pcb.kicad_pcb, pcb.step]
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2022-07-07 remove plating around switches
    [plate.kicad_pcb, plate.kicad_sch]
2022-08-31 Create right macro Lucy
    [pcb-B_Cu.gbl, pcb-B_Mask.gbs, pcb-B_Silkscreen.gbo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]
2022-08-31 changed name to Lucy left macro
    [pcb-B_Cu.gbl, pcb-B_Mask.gbs, pcb-B_Silkscreen.gbo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]
2022-08-31 update Plate A to include support for right macro
    [plate-B_Cu.gbr, plate-B_Mask.gbr, plate-B_Paste.gbr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]
2022-08-31 changed name to left macro
    [pcb.kicad_pcb, pcb.kicad_sch, pcb.sch]
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2022-09-11 removed bottom cutout for flex
    new case design doesn't need it
    [pcb-B_Cu.gbl, pcb-B_Mask.gbs, pcb-B_Silkscreen.gbo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]
2023-01-25 remove flex cuts and encoder
    [pcb-B_Cu.gbl, pcb-B_Mask.gbs, pcb-B_Silkscreen.gbo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]
2023-01-25 remove flex cuts, move mounting points
    [plate-B_Cu.gbr, plate-B_Mask.gbr, plate-B_Paste.gbr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]
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2023-02-06 add 3d models to kicad footprints
    [pcb.kicad_pcb, pcb.kicad_sch]
2023-02-23 recessed USB port
    moved the usb port back a lot to make the case easier when using UDB
    [pcb-B_Cu.gbl, pcb-B_Mask.gbs, pcb-B_Silkscreen.gbo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]
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2023-03-27 moved USB port data line resistors
    also added 3d models, etc.
    [2U.dxf, 2U_switch_plate_cutout.dxf, 3313J-1-202E.stp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]
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2023-03-31 all new routing for -MU MCU. v3.0
    [2U.dxf, 2U_switch_plate_cutout.dxf, 3313J-1-202E.stp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]
2023-03-31 remove stiffer plate
    [plate-B_Cu.gbr, plate-B_Mask.gbr, plate-B_Paste.gbr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]
2023-03-31 replace plate files
    [plate-B_Cu.gbr, plate-B_Mask.gbr, plate-B_Paste.gbr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]
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2023-03-31 update plate and add gerbers for FR4
    [plate-B_Cu.gbr, plate-B_Mask.gbr, plate-B_Paste.gbr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]
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2023-04-01 replaced SRV05-4 footprint
    [pcb.kicad_pcb, pcb.kicad_sch]
2023-04-12 add hand solderable pcb
    [2U.dxf, 2U_switch_plate_cutout.dxf, 3313J-1-202E.stp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]
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2023-04-23 replace mx footprint with marbast footprints
    [CON_BM02B-ACHSS.step, CON_HytePro_M411P_Plug_1x04.step, CON_HytePro_M411P_Receptacle_1x04.step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]
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2023-05-19 fixed macro gap
    stupid me had a 3/8" gap, and should have been 3/16" (0.25u vs 0.5u)
    [2U.dxf, 2U_switch_plate_cutout.dxf, 3313J-1-202E.stp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]
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
